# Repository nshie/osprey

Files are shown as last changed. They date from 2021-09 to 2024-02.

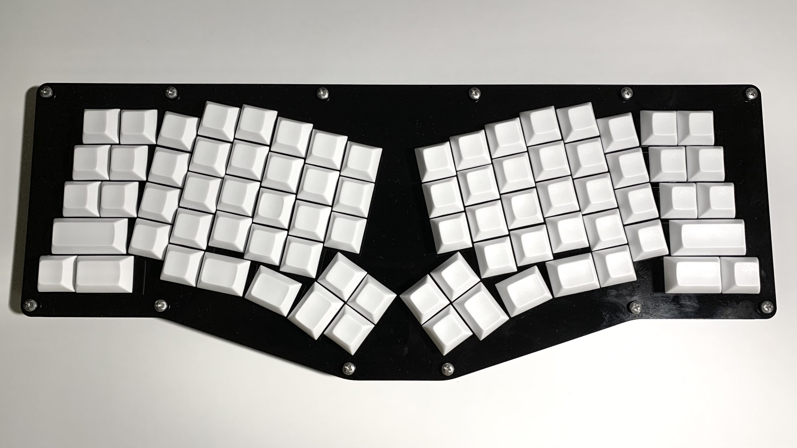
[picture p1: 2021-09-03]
photos/osprey-head-on.jpg

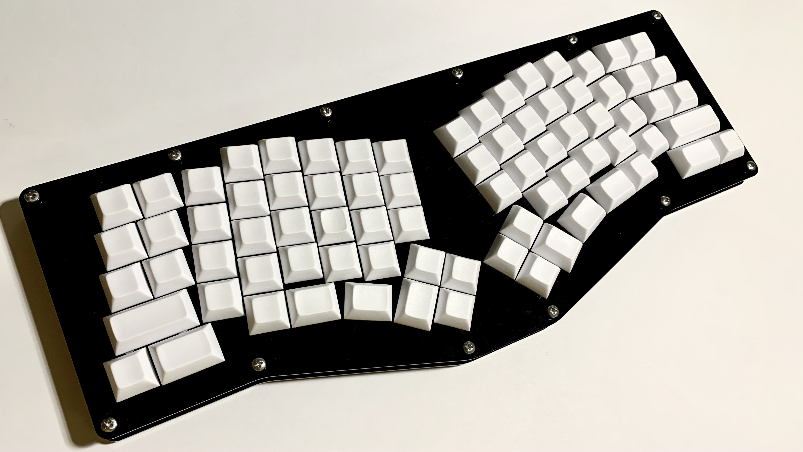
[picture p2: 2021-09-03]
photos/osprey-angle.jpg

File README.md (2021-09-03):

# Osprey
A unibody ergonomic ortholinear keyboard
- ergonomic wrist angle
- ortholinear columnar-stagger
- 60% layout (~ish)
- thumb clusters for modifiers and chording
- kailh hotswap sockets
- USB-C

### Features to change:
- leds in the pcb are not properly implemented with capacitors, WOULD NOT recommend building this board with the leds
- pcb uses 0805 diode pads; might have some difficulty finding them (0603 will work on the pcb)

osprey-angle

## Important Note:
This board is very much a prototype, and I would not recommend using the files without modification.

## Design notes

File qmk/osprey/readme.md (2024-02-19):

# Osprey

Osprey

A custom nonsplit ergonomic keyboard with 60% form factor

* Keyboard Maintainer: [phloamy](https://github.com/phloamy)
* Hardware Supported: Osprey pcb

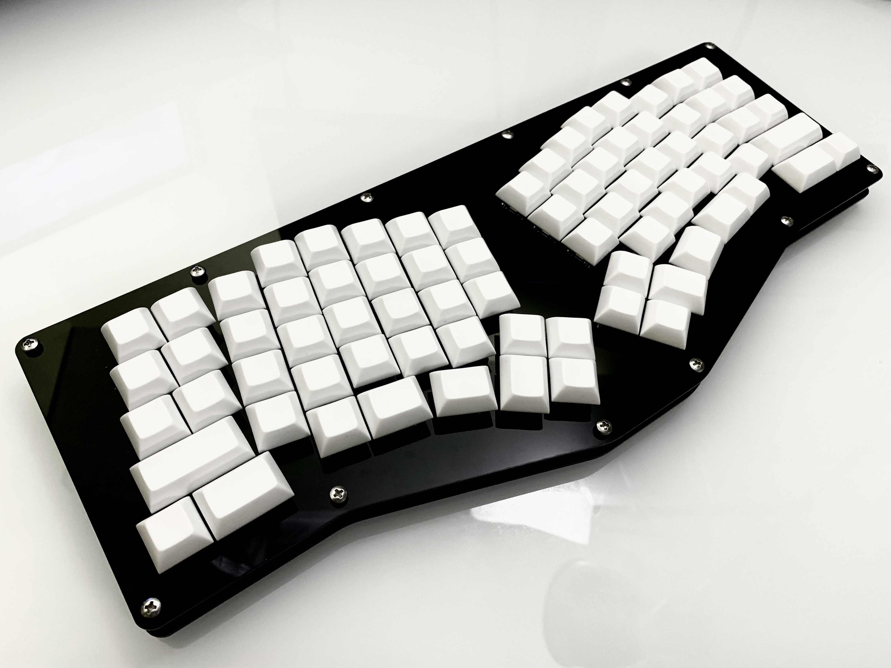
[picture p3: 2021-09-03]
photos/osprey-angle-flare.jpg

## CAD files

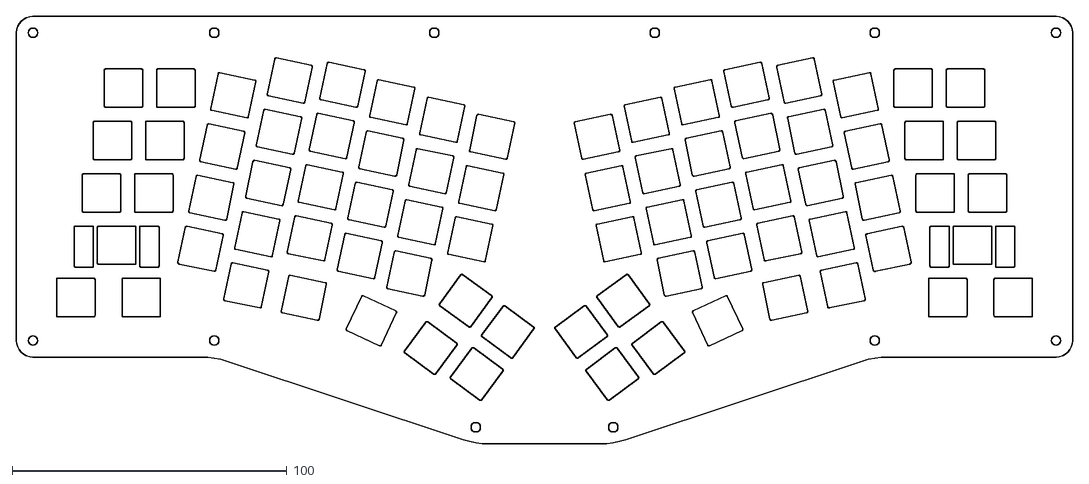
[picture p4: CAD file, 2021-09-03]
case/top-plate.dxf
384.2 x 155.5

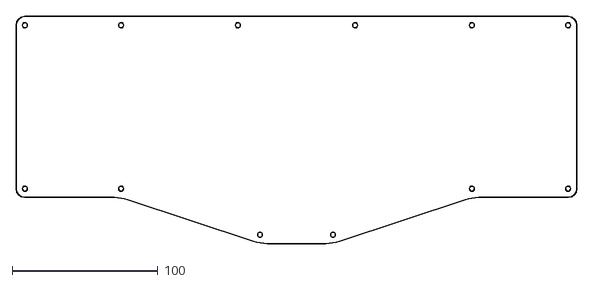
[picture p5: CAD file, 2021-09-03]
nonsplit-ergo-case-bottom-plate-2d.dxf
384.2 x 155.5

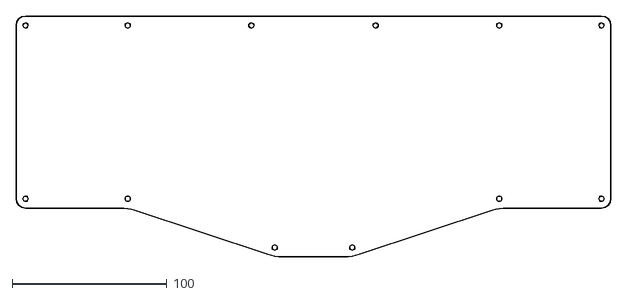
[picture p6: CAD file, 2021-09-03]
case/bottom-plate.dxf
384.2 x 155.5

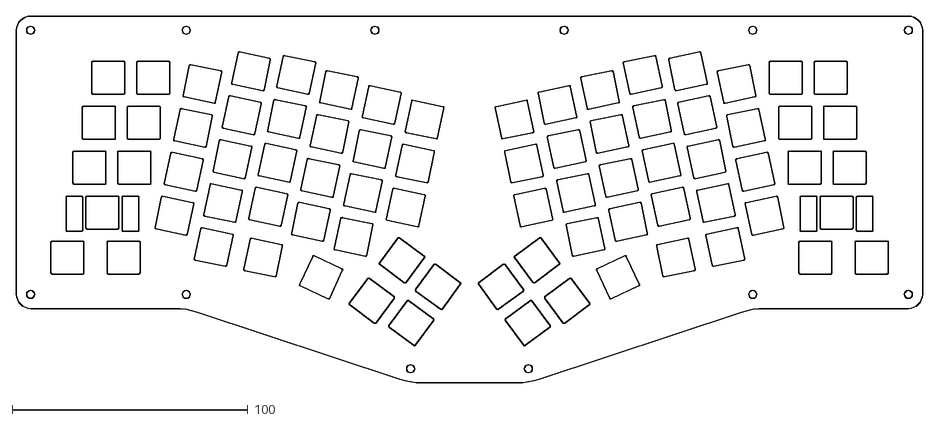
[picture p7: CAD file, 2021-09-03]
nonsplit-ergo-case-top-plate-2d.dxf
384.2 x 155.5

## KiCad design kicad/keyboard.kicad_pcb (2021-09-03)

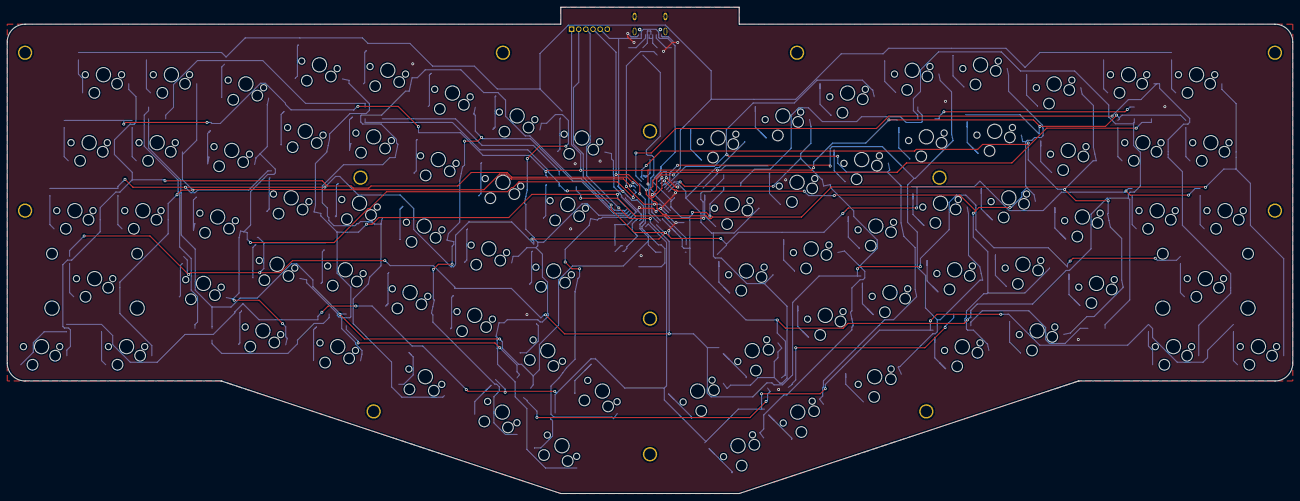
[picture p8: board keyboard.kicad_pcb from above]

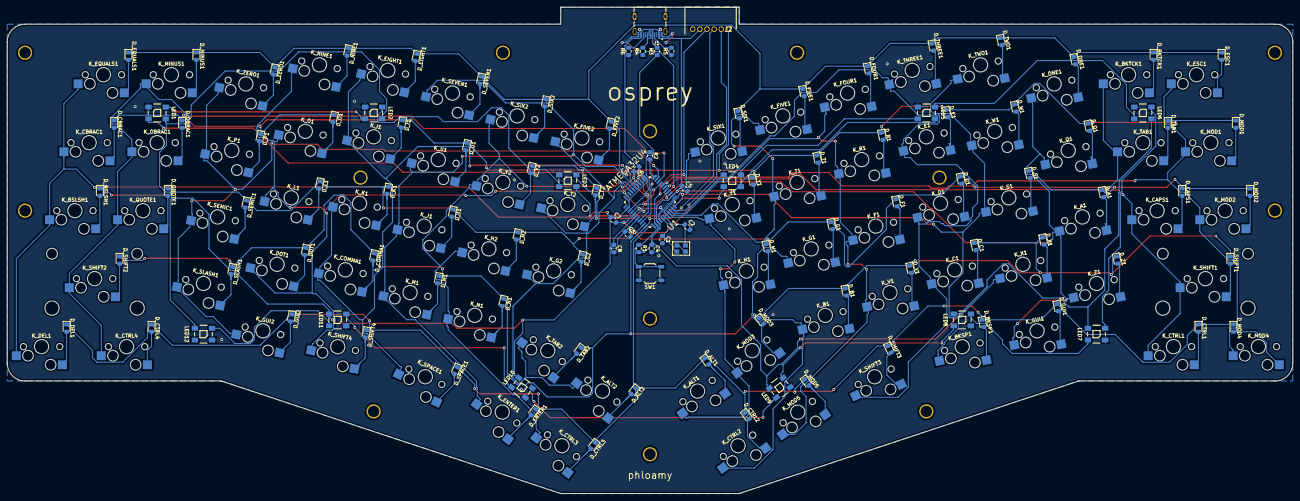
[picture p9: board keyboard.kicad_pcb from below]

Board: 2 copper layers, 360.2 x 136.3 mm, 200 parts (109 on the bottom side), 124 nets.

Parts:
C1, C2: 22p; C_0805_2012Metric_Pad1.15x1.40mm_HandSolder
C3, C4, C5, C6: 0.1u; C_0805_2012Metric_Pad1.15x1.40mm_HandSolder
C7: 4.7u; C_0805_2012Metric_Pad1.15x1.40mm_HandSolder
C8: 1u; C_0805_2012Metric_Pad1.15x1.40mm_HandSolder
D_A1: D; D_0805_2012Metric_Pad1.15x1.40mm_HandSolder
D_ALT1, D_ALT2: D; D_0805_2012Metric_Pad1.15x1.40mm_HandSolder
D_B1: D; D_0805_2012Metric_Pad1.15x1.40mm_HandSolder
D_BKSP1: D; D_0805_2012Metric_Pad1.15x1.40mm_HandSolder
D_BKTCK1: D; D_0805_2012Metric_Pad1.15x1.40mm_HandSolder
D_BSLSH1: D; D_0805_2012Metric_Pad1.15x1.40mm_HandSolder
D_C1: D; D_0805_2012Metric_Pad1.15x1.40mm_HandSolder
D_CAPS1: D; D_0805_2012Metric_Pad1.15x1.40mm_HandSolder
D_CBRAC1: D; D_0805_2012Metric_Pad1.15x1.40mm_HandSolder
D_COMMA1: D; D_0805_2012Metric_Pad1.15x1.40mm_HandSolder
D_CTRL1, D_CTRL2, D_CTRL3, D_CTRL4: D; D_0805_2012Metric_Pad1.15x1.40mm_HandSolder
D_D1: D; D_0805_2012Metric_Pad1.15x1.40mm_HandSolder
D_DEL1: D; D_0805_2012Metric_Pad1.15x1.40mm_HandSolder
D_DOT1: D; D_0805_2012Metric_Pad1.15x1.40mm_HandSolder
D_E1: D; D_0805_2012Metric_Pad1.15x1.40mm_HandSolder
D_EIGHT1: D; D_0805_2012Metric_Pad1.15x1.40mm_HandSolder
D_ENTER1: D; D_0805_2012Metric_Pad1.15x1.40mm_HandSolder
D_EQUALS1: D; D_0805_2012Metric_Pad1.15x1.40mm_HandSolder
D_ESC1: D; D_0805_2012Metric_Pad1.15x1.40mm_HandSolder
D_F1: D; D_0805_2012Metric_Pad1.15x1.40mm_HandSolder
D_FIVE1, D_FIVE2: D; D_0805_2012Metric_Pad1.15x1.40mm_HandSolder
D_FOUR1: D; D_0805_2012Metric_Pad1.15x1.40mm_HandSolder
D_G1, D_G2: D; D_0805_2012Metric_Pad1.15x1.40mm_HandSolder
D_GUI1, D_GUI2: D; D_0805_2012Metric_Pad1.15x1.40mm_HandSolder
D_H1, D_H2: D; D_0805_2012Metric_Pad1.15x1.40mm_HandSolder
D_I1: D; D_0805_2012Metric_Pad1.15x1.40mm_HandSolder
D_J1: D; D_0805_2012Metric_Pad1.15x1.40mm_HandSolder
D_K1: D; D_0805_2012Metric_Pad1.15x1.40mm_HandSolder
D_L1: D; D_0805_2012Metric_Pad1.15x1.40mm_HandSolder
D_M1: D; D_0805_2012Metric_Pad1.15x1.40mm_HandSolder
D_MINUS1: D; D_0805_2012Metric_Pad1.15x1.40mm_HandSolder
D_MOD1, D_MOD2, D_MOD3, D_MOD4, D_MOD5: D; D_0805_2012Metric_Pad1.15x1.40mm_HandSolder
D_N1: D; D_0805_2012Metric_Pad1.15x1.40mm_HandSolder
D_NINE1: D; D_0805_2012Metric_Pad1.15x1.40mm_HandSolder
D_O1: D; D_0805_2012Metric_Pad1.15x1.40mm_HandSolder
D_OBRAC1: D; D_0805_2012Metric_Pad1.15x1.40mm_HandSolder
D_ONE1: D; D_0805_2012Metric_Pad1.15x1.40mm_HandSolder
D_P1: D; D_0805_2012Metric_Pad1.15x1.40mm_HandSolder
D_Q1: D; D_0805_2012Metric_Pad1.15x1.40mm_HandSolder
D_QUOTE1: D; D_0805_2012Metric_Pad1.15x1.40mm_HandSolder
D_R1: D; D_0805_2012Metric_Pad1.15x1.40mm_HandSolder
D_S1: D; D_0805_2012Metric_Pad1.15x1.40mm_HandSolder
D_SEMIC1: D; D_0805_2012Metric_Pad1.15x1.40mm_HandSolder
D_SEVEN1: D; D_0805_2012Metric_Pad1.15x1.40mm_HandSolder
D_SHIFT1, D_SHIFT2, D_SHIFT3, D_SHIFT4: D; D_0805_2012Metric_Pad1.15x1.40mm_HandSolder
D_SIX1, D_SIX2: D; D_0805_2012Metric_Pad1.15x1.40mm_HandSolder
D_SLASH1: D; D_0805_2012Metric_Pad1.15x1.40mm_HandSolder
D_SPACE1: D; D_0805_2012Metric_Pad1.15x1.40mm_HandSolder
D_T1, D_T2: D; D_0805_2012Metric_Pad1.15x1.40mm_HandSolder
D_TAB1, D_TAB2: D; D_0805_2012Metric_Pad1.15x1.40mm_HandSolder
D_THREE1: D; D_0805_2012Metric_Pad1.15x1.40mm_HandSolder
D_TWO1: D; D_0805_2012Metric_Pad1.15x1.40mm_HandSolder
D_U1: D; D_0805_2012Metric_Pad1.15x1.40mm_HandSolder
D_V1: D; D_0805_2012Metric_Pad1.15x1.40mm_HandSolder
D_W1: D; D_0805_2012Metric_Pad1.15x1.40mm_HandSolder
D_X1: D; D_0805_2012Metric_Pad1.15x1.40mm_HandSolder
D_Y1, D_Y2: D; D_0805_2012Metric_Pad1.15x1.40mm_HandSolder
D_Z1: D; D_0805_2012Metric_Pad1.15x1.40mm_HandSolder
D_ZERO1: D; D_0805_2012Metric_Pad1.15x1.40mm_HandSolder
HOLE1, HOLE2, HOLE3, HOLE4, HOLE5, HOLE6, HOLE7, HOLE8, HOLE9, HOLE10, HOLE11, HOLE12, HOLE13: HOLE_M3
J1: TYPE-C-31-M-12; HRO_TYPE-C-31-M-12
J2: DF3A-6P-2DS; SHDRRA6W60P0X200_1X6_1400X720X530P
K_A1: KEYSW; MXOnly-1U-Hotswap
K_ALT1, K_ALT2: KEYSW; MXOnly-1U-Hotswap
K_B1: KEYSW; MXOnly-1U-Hotswap
K_BKSP1: KEYSW; MXOnly-1.25U-Hotswap
K_BKTCK1: KEYSW; MXOnly-1U-Hotswap
K_BSLSH1: KEYSW; MXOnly-1U-Hotswap
K_C1: KEYSW; MXOnly-1U-Hotswap
K_CAPS1: KEYSW; MXOnly-1U-Hotswap
K_CBRAC1: KEYSW; MXOnly-1U-Hotswap
K_COMMA1: KEYSW; MXOnly-1U-Hotswap
K_CTRL1, K_CTRL4: KEYSW; MXOnly-1.5U-Hotswap
K_CTRL2, K_CTRL3: KEYSW; MXOnly-1U-Hotswap
K_D1: KEYSW; MXOnly-1U-Hotswap
K_DEL1: KEYSW; MXOnly-1U-Hotswap
K_DOT1: KEYSW; MXOnly-1U-Hotswap
K_E1: KEYSW; MXOnly-1U-Hotswap
K_EIGHT1: KEYSW; MXOnly-1U-Hotswap
K_ENTER1: KEYSW; MXOnly-1U-Hotswap
K_EQUALS1: KEYSW; MXOnly-1U-Hotswap
K_ESC1: KEYSW; MXOnly-1U-Hotswap
K_F1: KEYSW; MXOnly-1U-Hotswap
K_FIVE1, K_FIVE2: KEYSW; MXOnly-1U-Hotswap
K_FOUR1: KEYSW; MXOnly-1U-Hotswap
K_G1, K_G2: KEYSW; MXOnly-1U-Hotswap
K_GUI1, K_GUI2: KEYSW; MXOnly-1U-Hotswap
K_H1, K_H2: KEYSW; MXOnly-1U-Hotswap
K_I1: KEYSW; MXOnly-1U-Hotswap
K_J1: KEYSW; MXOnly-1U-Hotswap
K_K1: KEYSW; MXOnly-1U-Hotswap
K_L1: KEYSW; MXOnly-1U-Hotswap
K_M1: KEYSW; MXOnly-1U-Hotswap
K_MINUS1: KEYSW; MXOnly-1U-Hotswap
K_MOD1, K_MOD2, K_MOD3, K_MOD4, K_MOD5: KEYSW; MXOnly-1U-Hotswap
K_N1: KEYSW; MXOnly-1U-Hotswap
K_NINE1: KEYSW; MXOnly-1U-Hotswap
K_O1: KEYSW; MXOnly-1U-Hotswap
K_OBRAC1: KEYSW; MXOnly-1U-Hotswap
K_ONE1: KEYSW; MXOnly-1U-Hotswap
K_P1: KEYSW; MXOnly-1U-Hotswap
K_Q1: KEYSW; MXOnly-1U-Hotswap
K_QUOTE1: KEYSW; MXOnly-1U-Hotswap
K_R1: KEYSW; MXOnly-1U-Hotswap
K_S1: KEYSW; MXOnly-1U-Hotswap
K_SEMIC1: KEYSW; MXOnly-1U-Hotswap
K_SEVEN1: KEYSW; MXOnly-1U-Hotswap
K_SHIFT1, K_SHIFT2: KEYSW; MXOnly-2U-Hotswap-ReversedStabilizers
K_SHIFT3, K_SHIFT4: KEYSW; MXOnly-1.25U-Hotswap
K_SIX1, K_SIX2: KEYSW; MXOnly-1U-Hotswap
K_SLASH1: KEYSW; MXOnly-1U-Hotswap
K_SPACE1: KEYSW; MXOnly-1.25U-Hotswap
K_T1, K_T2: KEYSW; MXOnly-1U-Hotswap
K_TAB1, K_TAB2: KEYSW; MXOnly-1U-Hotswap
K_THREE1: KEYSW; MXOnly-1U-Hotswap
K_TWO1: KEYSW; MXOnly-1U-Hotswap
K_U1: KEYSW; MXOnly-1U-Hotswap
K_V1: KEYSW; MXOnly-1U-Hotswap
K_W1: KEYSW; MXOnly-1U-Hotswap
K_X1: KEYSW; MXOnly-1U-Hotswap
K_Y1, K_Y2: KEYSW; MXOnly-1U-Hotswap
K_Z1: KEYSW; MXOnly-1U-Hotswap
K_ZERO1: KEYSW; MXOnly-1U-Hotswap
LED1, LED2, LED3, LED4, LED5, LED6, LED7, LED8, LED9, LED10, LED11, LED12: WS2812B
R1, R2: 10k; R_0805_2012Metric_Pad1.15x1.40mm_HandSolder
R3, R4: 22; R_0805_2012Metric_Pad1.15x1.40mm_HandSolder
R5, R6: 5.1k; R_0805_2012Metric_Pad1.15x1.40mm_HandSolder
SW1: SW_PUSH; SW_SPST_TL3342
U1: ATMEGA32U4; ATmega32U4
X1: XTAL_GND; FA-238

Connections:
GND: C1.2, C2.2, C3.2, C4.2, C5.2, C6.2, C7.2, C8.2, J1.A1B12, J1.B1A12, J1.S1, J1.S2, J1.S3, J1.S4, J2.6, LED1.3, LED2.3, LED3.3, LED4.3, LED5.3, LED6.3, LED7.3, LED8.3, LED9.3, LED10.3, LED11.3, LED12.3, R2.1, R5.1, R6.1, SW1.1, U1.5, U1.15, U1.23, U1.35, U1.43, X1.3
unnamed: C1.1, U1.16, X1.1
unnamed: C2.1, U1.17, X1.2
unnamed: C8.1, U1.6
unnamed: D_A1.2, K_A1.2
unnamed: D_ALT1.2, K_ALT1.2
unnamed: D_ALT2.2, K_ALT2.2
unnamed: D_B1.2, K_B1.2
unnamed: D_BKSP1.2, K_BKSP1.2
unnamed: D_BKTCK1.2, K_BKTCK1.2
unnamed: D_BSLSH1.2, K_BSLSH1.2
unnamed: D_C1.2, K_C1.2
unnamed: D_CAPS1.2, K_CAPS1.2
unnamed: D_CBRAC1.2, K_CBRAC1.2
unnamed: D_COMMA1.2, K_COMMA1.2
unnamed: D_CTRL1.2, K_CTRL1.2
unnamed: D_CTRL2.2, K_CTRL2.2
unnamed: D_CTRL3.2, K_CTRL3.2
unnamed: D_CTRL4.2, K_CTRL4.2
unnamed: D_D1.2, K_D1.2
unnamed: D_DEL1.2, K_DEL1.2
unnamed: D_DOT1.2, K_DOT1.2
unnamed: D_E1.2, K_E1.2
unnamed: D_EIGHT1.2, K_EIGHT1.2
unnamed: D_ENTER1.2, K_ENTER1.2
unnamed: D_EQUALS1.2, K_EQUALS1.2
unnamed: D_ESC1.2, K_ESC1.2
unnamed: D_F1.2, K_F1.2
unnamed: D_FIVE1.2, K_FIVE1.2
unnamed: D_FIVE2.2, K_FIVE2.2
unnamed: D_FOUR1.2, K_FOUR1.2
unnamed: D_G1.2, K_G1.2
unnamed: D_G2.2, K_G2.2
unnamed: D_GUI1.2, K_GUI1.2
unnamed: D_GUI2.2, K_GUI2.2
unnamed: D_H1.2, K_H1.2
unnamed: D_H2.2, K_H2.2
unnamed: D_I1.2, K_I1.2
unnamed: D_J1.2, K_J1.2
unnamed: D_K1.2, K_K1.2
unnamed: D_L1.2, K_L1.2
unnamed: D_M1.2, K_M1.2
unnamed: D_MINUS1.2, K_MINUS1.2
unnamed: D_MOD1.2, K_MOD1.2
unnamed: D_MOD2.2, K_MOD2.2
unnamed: D_MOD3.2, K_MOD3.2
unnamed: D_MOD4.2, K_MOD4.2
unnamed: D_MOD5.2, K_MOD5.2
unnamed: D_N1.2, K_N1.2
unnamed: D_NINE1.2, K_NINE1.2
unnamed: D_O1.2, K_O1.2
unnamed: D_OBRAC1.2, K_OBRAC1.2
unnamed: D_ONE1.2, K_ONE1.2
unnamed: D_P1.2, K_P1.2
unnamed: D_Q1.2, K_Q1.2
unnamed: D_QUOTE1.2, K_QUOTE1.2
unnamed: D_R1.2, K_R1.2
unnamed: D_S1.2, K_S1.2
unnamed: D_SEMIC1.2, K_SEMIC1.2
unnamed: D_SEVEN1.2, K_SEVEN1.2
unnamed: D_SHIFT1.2, K_SHIFT1.2
unnamed: D_SHIFT2.2, K_SHIFT2.2
unnamed: D_SHIFT3.2, K_SHIFT3.2
unnamed: D_SHIFT4.2, K_SHIFT4.2
unnamed: D_SIX1.2, K_SIX1.2
unnamed: D_SIX2.2, K_SIX2.2
unnamed: D_SLASH1.2, K_SLASH1.2
unnamed: D_SPACE1.2, K_SPACE1.2
unnamed: D_T1.2, K_T1.2
unnamed: D_T2.2, K_T2.2
unnamed: D_TAB1.2, K_TAB1.2
unnamed: D_TAB2.2, K_TAB2.2
unnamed: D_THREE1.2, K_THREE1.2
unnamed: D_TWO1.2, K_TWO1.2
unnamed: D_U1.2, K_U1.2
unnamed: D_V1.2, K_V1.2
unnamed: D_W1.2, K_W1.2
unnamed: D_X1.2, K_X1.2
unnamed: D_Y1.2, K_Y1.2
unnamed: D_Y2.2, K_Y2.2
unnamed: D_Z1.2, K_Z1.2
unnamed: D_ZERO1.2, K_ZERO1.2
unnamed: J1.A5, R5.2
unnamed: J1.A6, J1.B6, R4.2
unnamed: J1.A7, J1.B7, R3.2
unnamed: J1.B5, R6.2
unnamed: LED1.2, LED2.4
unnamed: LED2.2, LED3.4
unnamed: LED3.2, LED4.4
unnamed: LED4.2, LED5.4
unnamed: LED5.2, LED6.4
unnamed: LED6.2, LED7.4
unnamed: LED7.2, LED8.4
unnamed: LED8.2, LED9.4
unnamed: LED10.2, LED11.4
unnamed: LED9.2, LED10.4
unnamed: LED11.2, LED12.4
unnamed: R2.2, U1.33
unnamed: R3.1, U1.3
unnamed: R4.1, U1.4
VCC: C3.1, C4.1, C5.1, C6.1, C7.1, J1.A4B9, J1.B4A9, J2.5, LED1.1, LED2.1, LED3.1, LED4.1, LED5.1, LED6.1, LED7.1, LED8.1, LED9.1, LED10.1, LED11.1, LED12.1, R1.2, U1.2, U1.7, U1.14, U1.24, U1.34, U1.44
col0: K_ESC1.1, K_MOD1.1, K_MOD2.1, K_MOD4.1, U1.29
col1: K_BKTCK1.1, K_CAPS1.1, K_CTRL1.1, K_SHIFT1.1, K_TAB1.1, U1.28
col2: K_A1.1, K_GUI1.1, K_ONE1.1, K_Q1.1, K_Z1.1, U1.27
col3: K_BKSP1.1, K_S1.1, K_TWO1.1, K_W1.1, K_X1.1, U1.22
col4: K_C1.1, K_D1.1, K_E1.1, K_SHIFT3.1, K_THREE1.1, U1.21
col5: K_F1.1, K_FOUR1.1, K_MOD5.1, K_R1.1, K_V1.1, U1.20
col6: K_B1.1, K_CTRL2.1, K_FIVE1.1, K_G1.1, K_T1.1, U1.19
col7: K_ALT1.1, K_H1.1, K_MOD3.1, K_SIX1.1, K_Y1.1, U1.18
col8: K_ALT2.1, K_FIVE2.1, K_G2.1, K_T2.1, K_TAB2.1, U1.41
col9: K_CTRL3.1, K_H2.1, K_N1.1, K_SIX2.1, K_Y2.1, U1.40
col10: K_ENTER1.1, K_J1.1, K_M1.1, K_SEVEN1.1, K_U1.1, U1.39
col11: K_COMMA1.1, K_EIGHT1.1, K_I1.1, K_K1.1, K_SPACE1.1, U1.38
col12: K_DOT1.1, K_L1.1, K_NINE1.1, K_O1.1, K_SHIFT4.1, U1.37
col13: K_GUI2.1, K_P1.1, K_SEMIC1.1, K_SLASH1.1, K_ZERO1.1, U1.32
col14: K_CTRL4.1, K_MINUS1.1, K_OBRAC1.1, K_QUOTE1.1, K_SHIFT2.1, U1.31
col15: K_BSLSH1.1, K_CBRAC1.1, K_DEL1.1, K_EQUALS1.1, U1.30
led: LED1.4, U1.36
reset: J2.4, R1.1, SW1.2, U1.13
row0: D_BKTCK1.1, D_EIGHT1.1, D_EQUALS1.1, D_ESC1.1, D_FIVE1.1, D_FIVE2.1, D_FOUR1.1, D_MINUS1.1, D_NINE1.1, D_ONE1.1, D_SEVEN1.1, D_SIX1.1, D_SIX2.1, D_THREE1.1, D_TWO1.1, D_ZERO1.1, U1.8
row1: D_CBRAC1.1, D_E1.1, D_I1.1, D_MOD1.1, D_O1.1, D_OBRAC1.1, D_P1.1, D_Q1.1, D_R1.1, D_T1.1, D_T2.1, D_TAB1.1, D_U1.1, D_W1.1, D_Y1.1, D_Y2.1, J2.1, U1.9
row2: D_A1.1, D_BSLSH1.1, D_CAPS1.1, D_D1.1, D_F1.1, D_G1.1, D_G2.1, D_H1.1, D_H2.1, D_J1.1, D_K1.1, D_L1.1, D_MOD2.1, D_QUOTE1.1, D_S1.1, D_SEMIC1.1, J2.2, U1.10
row3: D_B1.1, D_C1.1, D_COMMA1.1, D_DOT1.1, D_M1.1, D_MOD3.1, D_N1.1, D_SHIFT1.1, D_SHIFT2.1, D_SLASH1.1, D_TAB2.1, D_V1.1, D_X1.1, D_Z1.1, J2.3, U1.11
row4: D_ALT1.1, D_ALT2.1, D_BKSP1.1, D_CTRL1.1, D_CTRL2.1, D_CTRL3.1, D_CTRL4.1, D_DEL1.1, D_ENTER1.1, D_GUI1.1, D_GUI2.1, D_MOD4.1, D_MOD5.1, D_SHIFT3.1, D_SHIFT4.1, D_SPACE1.1, U1.12

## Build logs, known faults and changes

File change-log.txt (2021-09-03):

// CHANGE LOG
// DOCUMENTING CHANGES AND REASONS FOR CHANGES
// ALSO DOCUMENTING SHORTCOMINGS OF EACH ITERATION
// ADDED SMALL NOTES TO UNDERSTAND THOUGHT PROCESS

// REV 1

+ more ergonomic
+ dedicated esc / grave key
+ decent form factor

- not symmetrical
- shift kind of far
- spacebar positioning slightly uncomfortable
- a few too many empty keys (undecided how to hit those [like what fingers] and what to put there)

* first pass at 60% ergo non split
* modeled after TGR Alice slightly

// REV 2

+ removed right side extra column for symmetry -- also moves shift closer

- don't like how the MO(1) and Enter keys are so far away, very hard to hit
- also don't like the thumb keys in general are hard to hit
- q and p are hard to hit with pinky -- in general pinky keys slightly out of reach

// REV 3

+ addresses hard to reach pinky keys by lowering pinky columns
+ pinky columns in home position are also tilted now
+ angle of tilt is 12 degrees
+ thumb clusters are tilted as well to give better ergonomics for thumb
+ alt extended to 1.5u instead of 1u (for larger surface area for thumb to hit [chose 1.5u for keycap compatibility])

- thumb ctrl is hard to reach, probably swap for where alt is
- don't like how chording enter + space or MO(1) + backspace would be very difficult (for later potential stenography implementation)
- ctrl key position hard to reach in general, may remove ???
- pinky ctrl keys are still hard to reach
- oops, the j and l keys swapped in key placing

* of note, the main thumb keys have to be stabilized as it is, don't know if that will come into play later
* also noteworthy, a few design considerations will be based upon potential stenography usage, mainly how easy it is to chord thumb cluster keys
* as it stands, the keyboard form factor is also a consideration, but later revisions may not take that into account (going for a "flatter" wider and less tall shape [middle part has small protrusion -- to be expected and welcomed])

// REV 4

+ thumb ctrl is in accessible spot
+ ctrl + alt chording for key combinations such as ctrl + alt + shift + r for OBS record shortcut
+ pinky ctrl keys moved in, now space for additional key on the outside (infrequent use key)

- still don't like the alt key position, seems very hard to reach
- ambiguous use of the keys underneath x, c, <, and > keys. don't want to remove for form factor sake, but not really sure what to do with them yet
- keycaps call for 4 1.5u keys which is not easily attainable from a full size set

// REV 5

+ got rid of the two many 1.5u keys issue (now only 2 being used)
+ only 4 2u keys in use, meaning it's possible to use only a full size set for this board
+ chording of keys is very easy now (MO(1) + ctrl on left, enter + ctrl on right)
+ more thumb keys in use, mostly pretty accessible
+ just remembered that 1.25u keys are a thing, now 6 in use (out of 7 on full size set), all on thumb keys
+ all thumb keys are curved in a slight arc towards thumb

- not really sure what to do with the key on top of the vertical 1.25u
- duplicate ctrl keys on left side, not really sure what to think about that yet

* ideaology shift: thumb resting position should be more outward (relative to center of keyboard, inward if you are thinking relative to palm)
* more thumb keys used now, not sure if that is good or bad
* honestly way too many keys, don't feel like there's a need for that many, but it helps the form factor so :shrug:

// REV 6

+ middle finger column in line with ring and pointer finger column (better for games and numpad compatibility)
+ button underneath x and > keys switched to left and right windows key respectively
+ button on top of MO(1) switched to m (for games, m is usually map)

* this allows for esdf to comfortably be default position for games

// REV 7

+ pointer finger row raised a little because it's not a 0.25u difference from pointer homerow to one row over
+ thumb cluster second row shifted upwards to make overall form factor smaller (less of an angle in the case)
+ split right side caps and tab into 2 keys to allow for more layer keys (also keeps symmetry between left and right sides)
+ thumb cluster angle changed to match the pointer column change

- second row keys might be harder to reach now
- caps and tab will no longer "feel" like big keys, could be hard to get used to

// REV 8

+ just staggered the middle finger columns, but not by a whole 0.25u

* might make resting position for games (esdf) slightly more uncomfortable??? honestly not too much of a downside, it seems positive overall

// REV 9

+ shifted positions to prevent interference between caps with square corners (makes tolerances slightly higher; previously aligned based on rounded corners)
+ because of the slight shifts to prevent interference, angle of thumb cluster was decreased by 0.5u
+ added One Shot Layer key to left thumb cluster (easy access to fn keys)
+ added tab to right thumb cluster (to fix uncomfortable ring finger/pinky finger tab placement)

- widens overall keyboard with very slightly
- increases gap between angled keys and non angled keys (necessary to prevent interference, but slightly harder for fingers to reach)

* midline of keyboard should be 9.5u

// NOTE

* numbers get weird small decimal places, might make a tool to correct those

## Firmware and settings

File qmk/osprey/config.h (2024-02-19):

/*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
You should have received a copy of the GNU General Public License
along with this program.  If not, see <http://www.gnu.org/licenses/>.
*/

#pragma once

#include "config_common.h"

/* USB Device descriptor parameter */
#define VENDOR_ID       0xCAFE // https://pid.codes
#define PRODUCT_ID      0xACED
#define DEVICE_VER      0x0001
#define MANUFACTURER    Phloamy
#define PRODUCT         osprey
#define DESCRIPTION     A custom nonsplit ergo keyboard with 60% form factor

/* key matrix size */
#define MATRIX_ROWS 5
#define MATRIX_COLS 16

/*
 * Keyboard Matrix Assignments
 *
 * Change this to how you wired your keyboard
 * COLS: AVR pins used for columns, left to right
 * ROWS: AVR pins used for rows, top to bottom
 * DIODE_DIRECTION: COL2ROW = COL = Anode (+), ROW = Cathode (-, marked on diode)
 *                  ROW2COL = ROW = Anode (+), COL = Cathode (-, marked on diode)
 *
*/
#define MATRIX_ROW_PINS { B0, B1, B2, B3, B7 }
#define MATRIX_COL_PINS { B5, B4, D7, D5, D3, D2, D1, D0, F0, F1, F4, F5, F6, C7, C6, B6 }
#define UNUSED_PINS { D4, D6 }

/* COL2ROW, ROW2COL*/
#define DIODE_DIRECTION COL2ROW

//#define RGB_DI_PIN F7
#ifdef RGB_DI_PIN
#define RGBLIGHT_ANIMATIONS
#define RGBLED_NUM 1
#define RGBLIGHT_HUE_STEP 8
#define RGBLIGHT_SAT_STEP 8
#define RGBLIGHT_VAL_STEP 8
#define RGBLIGHT_SLEEP
#endif

/* Debounce reduces chatter (unintended double-presses) - set 0 if debouncing is not needed */
#define DEBOUNCE 5

/* define if matrix has ghost (lacks anti-ghosting diodes) */
//#define MATRIX_HAS_GHOST

/* number of backlight levels */

/* Mechanical locking support. Use KC_LCAP, KC_LNUM or KC_LSCR instead in keymap */
//#define LOCKING_SUPPORT_ENABLE
/* Locking resynchronize hack */
//#define LOCKING_RESYNC_ENABLE

/* If defined, GRAVE_ESC will always act as ESC when CTRL is held.
 * This is userful for the Windows task manager shortcut (ctrl+shift+esc).
 */
// #define GRAVE_ESC_CTRL_OVERRIDE

/*
 * Force NKRO
 *
 * Force NKRO (nKey Rollover) to be enabled by default, regardless of the saved
 * state in the bootmagic EEPROM settings. (Note that NKRO must be enabled in the
 * makefile for this to work.)
 *
 * If forced on, NKRO can be disabled via magic key (default = LShift+RShift+N)
 * until the next keyboard reset.
 *
 * NKRO may prevent your keystrokes from being detected in the BIOS, but it is
 * fully operational during normal computer usage.
 *
 * For a less heavy-handed approach, enable NKRO via magic key (LShift+RShift+N)
 * or via bootmagic (hold SPACE+N while plugging in the keyboard). Once set by
 * bootmagic, NKRO mode will always be enabled until it is toggled again during a
 * power-up.
 *
 */
//#define FORCE_NKRO

/*
 * Magic Key Options
 *
 * Magic keys are hotkey commands that allow control over firmware functions of
 * the keyboard. They are best used in combination with the HID Listen program,
 * found here: https://www.pjrc.com/teensy/hid_listen.html
 *
 * The options below allow the magic key functionality to be changed. This is
 * useful if your keyboard/keypad is missing keys and you want magic key support.
 *
 */

/* control how magic key switches layers */
//#define MAGIC_KEY_SWITCH_LAYER_WITH_FKEYS  true
//#define MAGIC_KEY_SWITCH_LAYER_WITH_NKEYS  true
//#define MAGIC_KEY_SWITCH_LAYER_WITH_CUSTOM false

/* override magic key keymap */
//#define MAGIC_KEY_SWITCH_LAYER_WITH_FKEYS
//#define MAGIC_KEY_SWITCH_LAYER_WITH_NKEYS
//#define MAGIC_KEY_SWITCH_LAYER_WITH_CUSTOM
//#define MAGIC_KEY_HELP1          H
//#define MAGIC_KEY_HELP2          SLASH
//#define MAGIC_KEY_DEBUG          D
//#define MAGIC_KEY_DEBUG_MATRIX   X
//#define MAGIC_KEY_DEBUG_KBD      K
//#define MAGIC_KEY_DEBUG_MOUSE    M
//#define MAGIC_KEY_VERSION        V
//#define MAGIC_KEY_STATUS         S
//#define MAGIC_KEY_CONSOLE        C
//#define MAGIC_KEY_LAYER0_ALT1    ESC
//#define MAGIC_KEY_LAYER0_ALT2    GRAVE
//#define MAGIC_KEY_LAYER0         0
//#define MAGIC_KEY_LAYER1         1
//#define MAGIC_KEY_LAYER2         2
//#define MAGIC_KEY_LAYER3         3
//#define MAGIC_KEY_LAYER4         4
//#define MAGIC_KEY_LAYER5         5
//#define MAGIC_KEY_LAYER6         6
//#define MAGIC_KEY_LAYER7         7
//#define MAGIC_KEY_LAYER8         8
//#define MAGIC_KEY_LAYER9         9
//#define MAGIC_KEY_BOOTLOADER     PAUSE
//#define MAGIC_KEY_LOCK           CAPS
//#define MAGIC_KEY_EEPROM         E
//#define MAGIC_KEY_NKRO           N
//#define MAGIC_KEY_SLEEP_LED      Z

/*
 * Feature disable options
 *  These options are also useful to firmware size reduction.
 */

/* disable debug and print */
/*
#ifndef NO_DEBUG
#define NO_DEBUG
#endif // !NO_DEBUG
#if !defined(NO_PRINT) && !defined(CONSOLE_ENABLE)
#define NO_PRINT
#endif // !NO_PRINT
*/

/* disable action features */
//#define NO_ACTION_LAYER
//#define NO_ACTION_TAPPING
//#define NO_ACTION_ONESHOT
#define NO_ACTION_MACRO
#define NO_ACTION_FUNCTION
#define DISABLE_LEADER

/*
 * MIDI options
 */
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

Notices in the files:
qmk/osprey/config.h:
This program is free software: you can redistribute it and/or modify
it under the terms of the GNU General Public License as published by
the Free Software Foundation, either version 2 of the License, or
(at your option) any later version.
